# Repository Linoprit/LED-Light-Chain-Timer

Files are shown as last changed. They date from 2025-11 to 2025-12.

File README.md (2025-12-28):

# LED-Light-Chain-Timer
A simple timer for LED chains. Switch it on and the LED chain lights for 6h, then it turns off for 18h, and so on.

Our LED string lights were going through a ton of batteries every year.
On the other side, we had plenty of old power tool batteries that would otherwise have been thrown away.
So I looked for a solution to use those batteries.

The problem with lithium batteries, however, is that they can't be completely discharged, so you need a protection circuit.

That's how I came across the TP4096 Protection Board, which also includes a charging circuit.

With the sheer number of string lights we have in use, it turned out that a timer circuit was necessary to automatically switch them on and off.

But there was no chance to timers ready-made anywhere, even though they're often found in the battery compartments of LED string lights.

That's why I built my own.

The usage of a CH32V003J4M6 allows to directly connect the schematic to a 3.6V LiIon-Battery. 

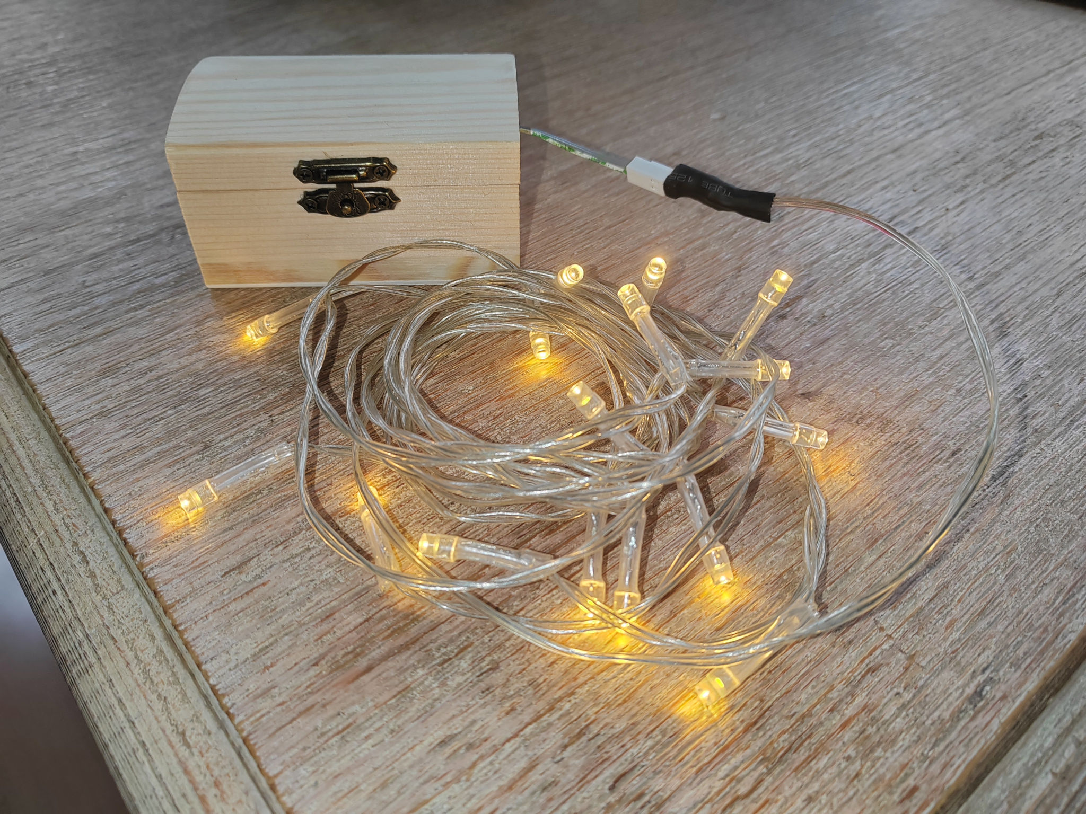
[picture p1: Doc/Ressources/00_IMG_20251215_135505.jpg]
 

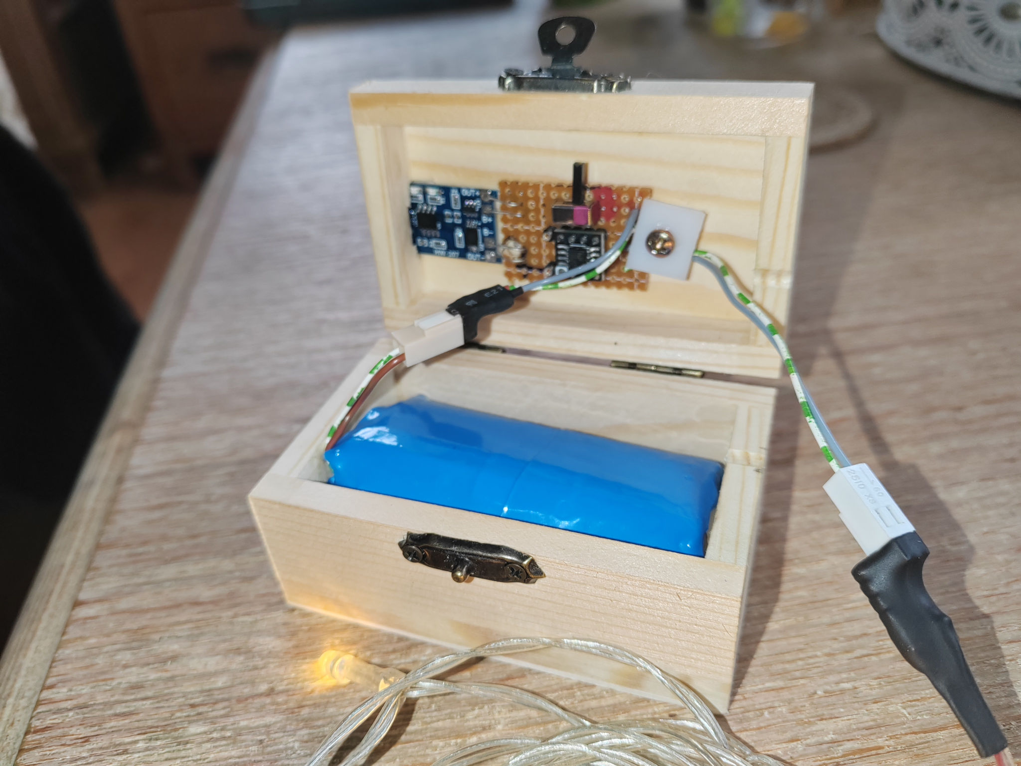
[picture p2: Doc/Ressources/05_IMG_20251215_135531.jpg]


To make it look nice, everything is packed in a wooden box.
The left image shows an older version with a switch. It turned out, that it could be omitted. 
The battery connection could therefore be soldered directly onto the protection board.
I built twenty of those timers, so this simplified things really. 

We could hide the plug of the LED string inside the housing, and of course run the cable to the outside through a hole.

Under the black heat shrink tubing, next to the connector, is a small piece of circuit board on which resistor limits the current through the LEDs to below 10mA. I set each of the different LED strings to this current, the brightness is okay like this. The values of the resistor varies from chain to chain and is approximately between 68 and 150 ohms. 

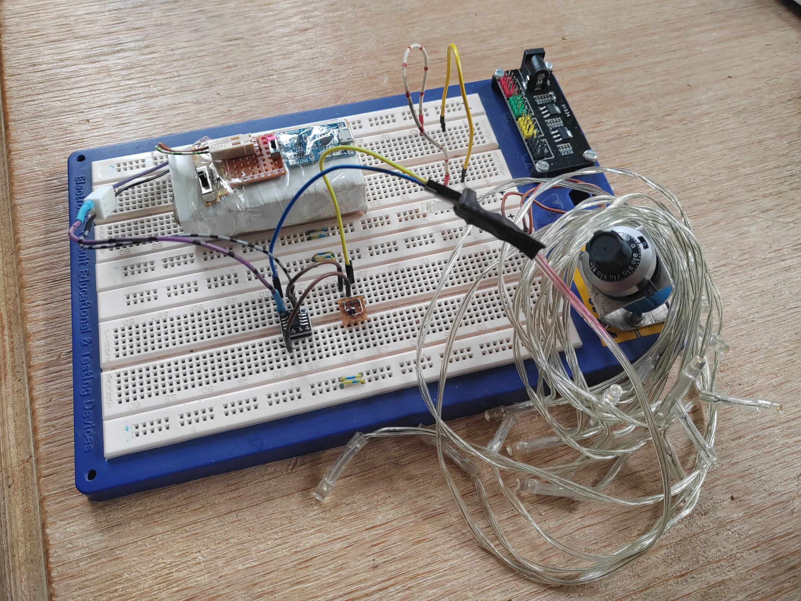
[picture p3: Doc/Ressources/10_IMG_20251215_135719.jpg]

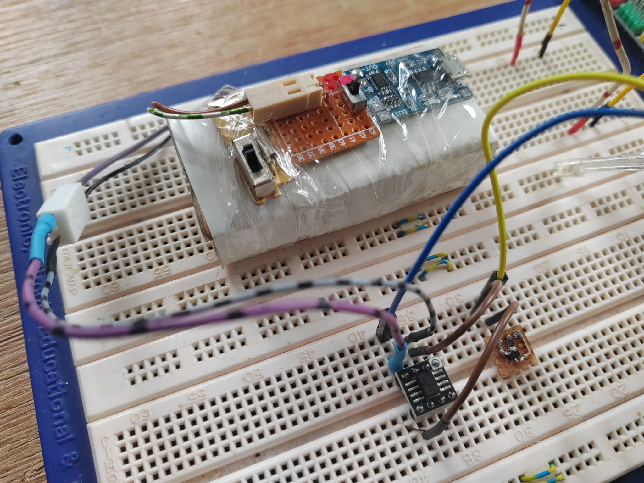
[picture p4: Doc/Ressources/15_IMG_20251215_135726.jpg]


Here is the breadboard setup shown, with a battery on which a TP4096 protection board is mounted.

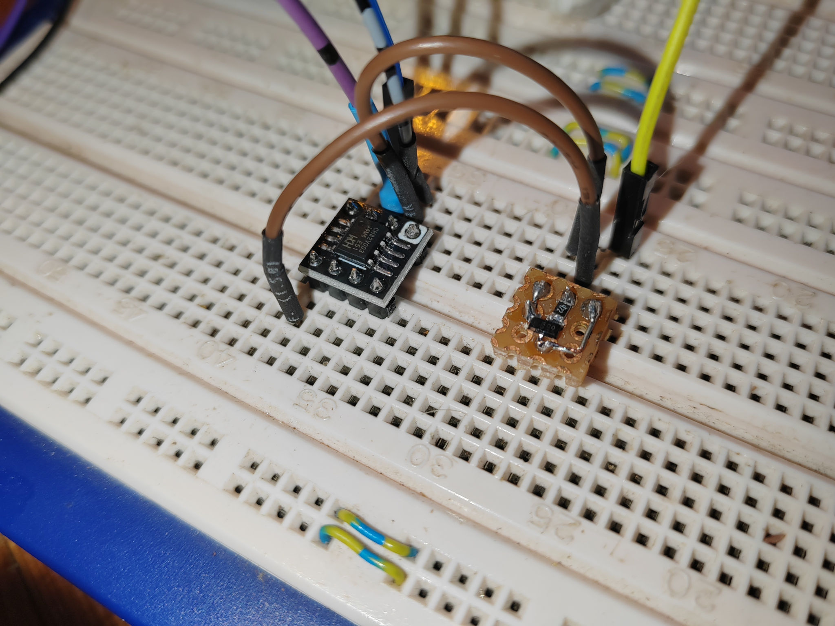
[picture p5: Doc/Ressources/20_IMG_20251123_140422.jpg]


On the left is the CH32v003J4N6 CPU, mounted on an adapter board. On the right is a transistor circuit, which was later omitted.

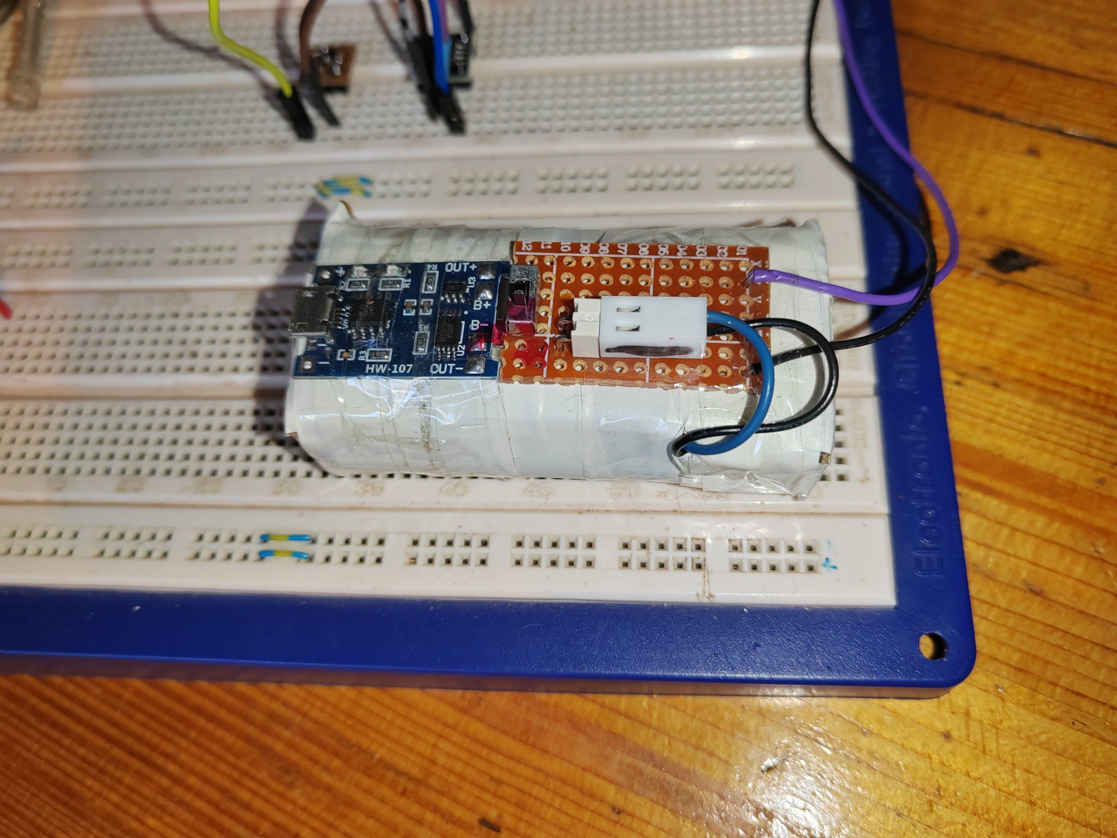
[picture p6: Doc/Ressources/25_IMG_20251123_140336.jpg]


Again, the battery with protection board.

## Parts you need, the links go to Aliexpress: 
- [CH32V003J4M6](https://de.aliexpress.com/item/1005008597052746.html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)
- [TP4056 Protection Board ()](https://de.aliexpress.com/item/1005007980101977.html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)
- [Adapter Boards for the CPUs](https://de.aliexpress.com/item/1005006991835764.html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)
- [Connectors](https://de.aliexpress.com/item/1005009345725922.html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)
- [Programmer](https://de.aliexpress.com/item/1005005180653105.html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)
> [!NOTE]
> You do need the WCH LinkE! The WCH-Link (without 'E') will not work.

Don't forget some boards, where you could solder everything on :-).

If you want a CPU with more pins use this one: [CH32V003F4P6](https://de.aliexpress.com/item/1005009062407508.html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)

## The Software...
...is really nothing special, there is only a main.c and a main.h. Simply use [PlatformIo](https://platformio.org/) to compile it. 

- [PIO Installation](https://platformio.org/install/ide)
- [PIO with VS Code ](https://platformio.org/platformio-ide)

You could use the Python script to measure some timings. Connect the TX-Pin of the CPU to the RX of the programmer. Then simply activate the defines in main.h. Don't activate both lines.

```
#define USE_UART_1MIN
#undef USE_UART_60MIN
```

I hope this little project is helpful to someone.

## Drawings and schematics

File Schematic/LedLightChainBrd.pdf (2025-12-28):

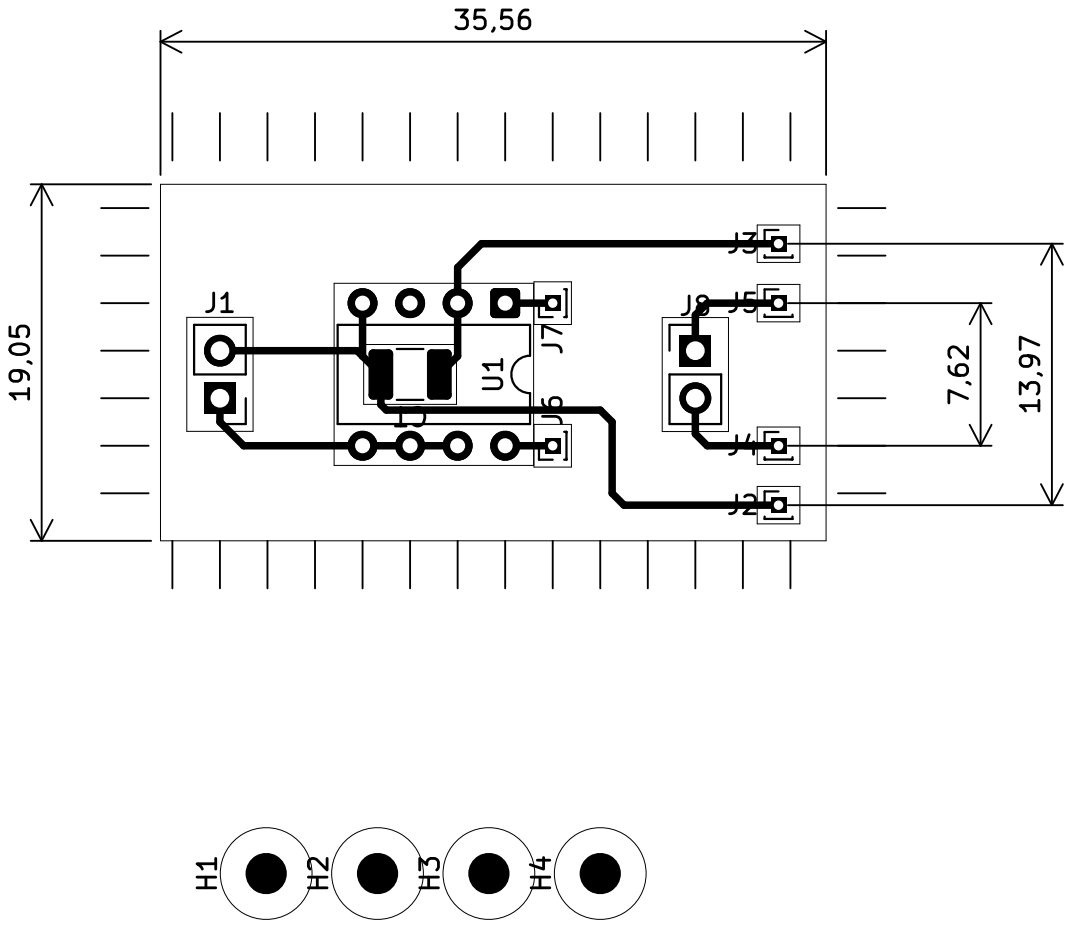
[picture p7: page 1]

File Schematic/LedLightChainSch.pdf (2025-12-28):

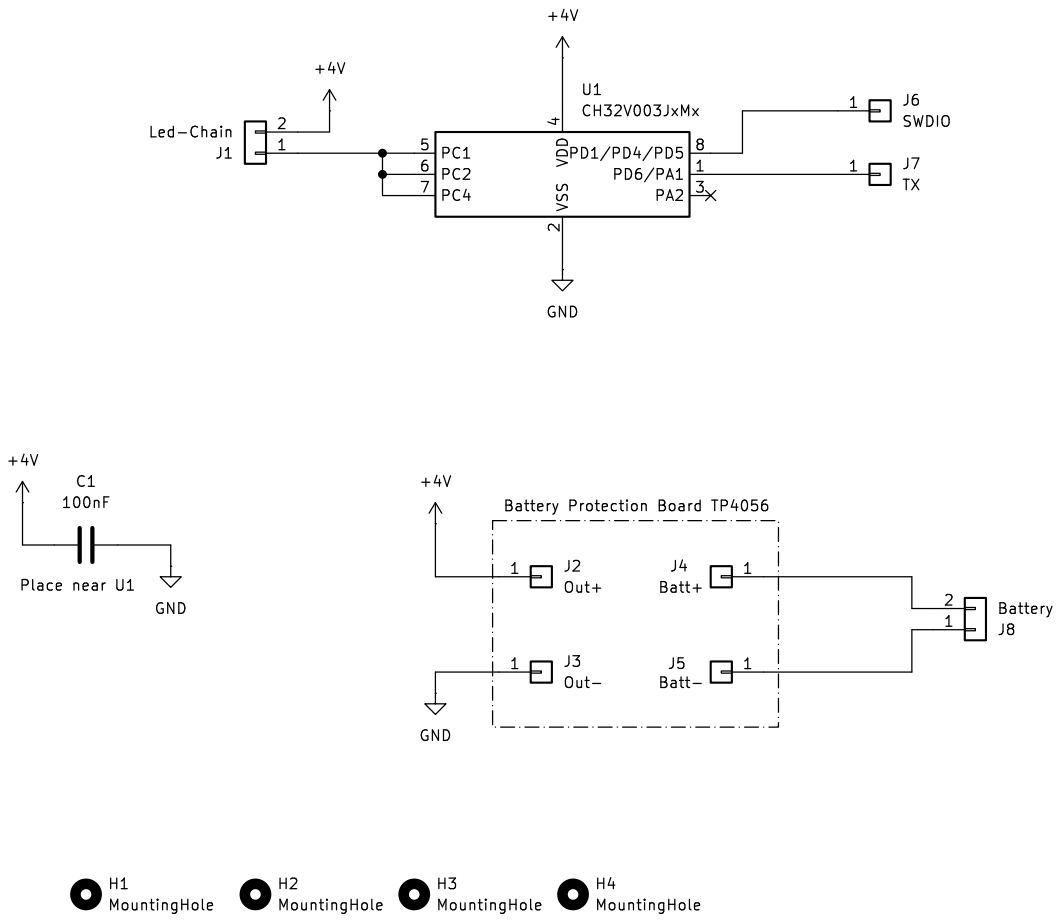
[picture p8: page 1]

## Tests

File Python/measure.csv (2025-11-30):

[B] Zeitdifferenz: 31 | 915 Sekunden
[B] Zeitdifferenz: 31 | 916 Sekunden
[B] Zeitdifferenz: 31 | 919 Sekunden
[B] Zeitdifferenz: 31 | 915 Sekunden
[B] Zeitdifferenz: 31 | 909 Sekunden
[B] Zeitdifferenz: 31 | 912 Sekunden
[B] Zeitdifferenz: 31 | 913 Sekunden
[B] Zeitdifferenz: 31 | 909 Sekunden
[B] Zeitdifferenz: 31 | 909 Sekunden
[B] Zeitdifferenz: 31 | 902 Sekunden
[B] Zeitdifferenz: 31 | 902 Sekunden
[B] Zeitdifferenz: 31 | 905 Sekunden
[B] Zeitdifferenz: 31 | 904 Sekunden
[B] Zeitdifferenz: 31 | 903 Sekunden
[B] Zeitdifferenz: 31 | 903 Sekunden
[B] Zeitdifferenz: 31 | 903 Sekunden
[B] Zeitdifferenz: 31 | 906 Sekunden
[B] Zeitdifferenz: 31 | 906 Sekunden
[B] Zeitdifferenz: 31 | 907 Sekunden
[B] Zeitdifferenz: 31 | 906 Sekunden
[B] Zeitdifferenz: 31 | 907 Sekunden
[B] Zeitdifferenz: 31 | 906 Sekunden
[B] Zeitdifferenz: 31 | 902 Sekunden

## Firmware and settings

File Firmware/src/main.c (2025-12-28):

/********************************** (C) COPYRIGHT *******************************
 * File Name          : main.c
 * Author             : WCH
 * Version            : V1.0.0
 * Date               : 2023/12/25
 * Description        : Main program body.
 *********************************************************************************
 * Copyright (c) 2021 Nanjing Qinheng Microelectronics Co., Ltd.
 * Attention: This software (modified or not) and binary are used for
 * microcontroller manufactured by Nanjing Qinheng Microelectronics.
 *******************************************************************************/

/*
 *@Note
 *CH32V003F4P6 - Interrupts
 *https://curiousscientist.tech/blog/ch32v003f4p6-interrupts
 */

#include "main.h"
#include "stdbool.h"

void countToTarget(uint32_t target);

void initializeTimer(uint16_t prsc, uint16_t arr)
{
    TIM_TimeBaseInitTypeDef TIM_TimeBaseStructure = {0};
    NVIC_InitTypeDef NVIC_InitStructure = {0};

    RCC_APB1PeriphClockCmd(RCC_APB1Periph_TIM2, ENABLE);

    TIM_TimeBaseStructure.TIM_Period = arr;
    TIM_TimeBaseStructure.TIM_Prescaler = prsc;
    TIM_TimeBaseStructure.TIM_ClockDivision = TIM_CKD_DIV1;
    TIM_TimeBaseStructure.TIM_CounterMode = TIM_CounterMode_Up;
    TIM_TimeBaseInit(TIM2, &TIM_TimeBaseStructure);

    TIM_SelectOutputTrigger(TIM2, TIM_TRGOSource_Update),
        TIM_ITConfig(TIM2, TIM_IT_Update, ENABLE);

    NVIC_InitStructure.NVIC_IRQChannel = TIM2_IRQn;
    NVIC_InitStructure.NVIC_IRQChannelPreemptionPriority = 0;
    NVIC_InitStructure.NVIC_IRQChannelSubPriority = 1;
    NVIC_InitStructure.NVIC_IRQChannelCmd = ENABLE;
    NVIC_Init(&NVIC_InitStructure);

    TIM_Cmd(TIM2, ENABLE);
}

#ifdef USE_UART_60MIN
const uint32_t targetPause = 3600 * 1;
const uint32_t targetActive = 3600 * 1;
#else
const uint32_t targetPause = 3600 * 18;
const uint32_t targetActive = 3600 * 6;
#endif

uint32_t actCount = 0;

#ifdef USE_UART_1MIN
bool done = false;
#endif

int main(void)
{
    NVIC_PriorityGroupConfig(NVIC_PriorityGroup_1);

    SystemCoreClockUpdate(); // initializeTimer(8049, 999); // 3612.578 Sekunden

    Delay_Init();
    Delay_Ms(1000);
    GPIOConfig();

#if defined(USE_UART_1MIN) || defined(USE_UART_60MIN)
    USART_Printf_Init(115200);
    printf("CH32V003 - Timer test\n");
#endif

#ifdef CRYSTAL
    initializeTimer(2666, 999); // 1kHz, 1s period
#endif
#ifdef BUILDIN_RC
    initializeTimer(8023, 999); // 1kHz, 1s period
#endif

    for (uint_fast8_t i = 0; i < 4; i++)
    {
        SwitchFairyPins(FAIRY_ON);
        Delay_Ms(300);
        SwitchFairyPins(FAIRY_OFF);
        Delay_Ms(300);
    }

    while (1)
    {
#ifdef USE_UART_60MIN
        printf("A\n");
#endif

        SwitchFairyPins(FAIRY_ON);
        countToTarget(targetActive);

#ifdef USE_UART_60MIN
        printf("B\n");
        printf("A\n");
#endif

        SwitchFairyPins(FAIRY_OFF);
        countToTarget(targetPause);

#ifdef USE_UART_60MIN
        printf("B\n");
#endif
    }
}

void countToTarget(uint32_t target)
{
#ifdef USE_UART_1MIN
    const uint32_t moduloCount = 60;
    printf("A\n");
#endif

    actCount = 0;
    while (actCount < target)
    {
        Delay_Ms(5);

#ifdef USE_UART_1MIN
        if (((actCount % moduloCount) == 0) && done == false)
        {
            done = true;
            printf("B\n");
            printf("A\n");
        }
        if ((actCount % moduloCount) != 0)
        {
            done = false;
        }
#endif
    }
}

void TIM2_IRQHandler(void) __attribute__((interrupt("WCH-Interrupt-fast")));
void TIM2_IRQHandler(void)
{
    if (TIM_GetITStatus(TIM2, TIM_IT_Update) != RESET)
    {
        TIM_ClearITPendingBit(TIM2, TIM_IT_Update);
        actCount++;

#ifdef F4P6
        GPIO_WriteBit(BLINKY_GPIO_PORT, BLINKY_GPIO_PIN,
                      (GPIO_ReadOutputDataBit(BLINKY_GPIO_PORT, BLINKY_GPIO_PIN) == Bit_SET) ? Bit_RESET : Bit_SET);
#endif
    }
}

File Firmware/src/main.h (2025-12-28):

#include <ch32v00x.h>
#include <debug.h>
#include <stdbool.h>


#undef USE_UART_1MIN
#undef USE_UART_60MIN

// Definitions to allow easy adjustment
#define BLINKY_GPIO_PORT GPIOD
#define BLINKY_GPIO_PIN GPIO_Pin_2
#define LED_FAIRY_PORT GPIOC
#ifdef J4M6
#define LED_FAIRY_PIN_01 GPIO_Pin_1
#define LED_FAIRY_PIN_02 GPIO_Pin_2
#define LED_FAIRY_PIN_03 GPIO_Pin_4
#else
#define LED_FAIRY_PIN GPIO_Pin_1
#define LED_FAIRY_PIN GPIO_Pin_2
#define LED_FAIRY_PIN GPIO_Pin_3
#endif
#define BLINKY_ON 1u
#define BLINKY_OFF 0u
#define FAIRY_ON 0u
#define FAIRY_OFF 1u
// #define BLINK_LENGTH_MS 100

// Error codes
#define OK 0
#define ERR_OUT_OF_RANGE 1

int main(void);
void parse_USART(void);

void NMI_Handler(void) __attribute__((interrupt("WCH-Interrupt-fast")));
void HardFault_Handler(void) __attribute__((interrupt("WCH-Interrupt-fast")));

void SwitchFairyPins(uint_fast8_t OnOrOff){
    GPIO_WriteBit(LED_FAIRY_PORT, LED_FAIRY_PIN_01, OnOrOff);
    GPIO_WriteBit(LED_FAIRY_PORT, LED_FAIRY_PIN_02, OnOrOff);
    GPIO_WriteBit(LED_FAIRY_PORT, LED_FAIRY_PIN_03, OnOrOff);
}

void GPIOConfig()
{
    GPIO_InitTypeDef GPIO_InitStructure = {0};

    RCC_APB2PeriphClockCmd(
        RCC_APB2Periph_GPIOA | RCC_APB2Periph_GPIOC | RCC_APB2Periph_GPIOD, ENABLE);
    RCC_APB1PeriphClockCmd(RCC_APB1Periph_PWR, ENABLE);
    GPIO_InitStructure.GPIO_Pin = GPIO_Pin_All;   // Apply the settings on all pins under the selected port
    GPIO_InitStructure.GPIO_Mode = GPIO_Mode_IPU; // Internal pull-up -> Contributes to power saving
    GPIO_Init(GPIOA, &GPIO_InitStructure);
    GPIO_Init(GPIOC, &GPIO_InitStructure);
    GPIO_Init(GPIOD, &GPIO_InitStructure);

    // ---------
    GPIO_InitStructure.GPIO_Mode = GPIO_Mode_Out_PP;
    GPIO_InitStructure.GPIO_Speed = GPIO_Speed_2MHz;

#ifdef F4P6
    GPIO_InitStructure.GPIO_Pin = BLINKY_GPIO_PIN;
    GPIO_Init(BLINKY_GPIO_PORT, &GPIO_InitStructure);
    GPIO_WriteBit(BLINKY_GPIO_PORT, BLINKY_GPIO_PIN, BLINKY_OFF);
#endif

    // ---------
    GPIO_InitStructure.GPIO_Pin = LED_FAIRY_PIN_01;
    GPIO_Init(LED_FAIRY_PORT, &GPIO_InitStructure);
    SwitchFairyPins(FAIRY_OFF);

    // remap UTX pin to PD6 on J4M6
#if (defined(USE_UART_1MIN) || defined(USE_UART_60MIN)) && defined J4M6
    RCC_APB2PeriphClockCmd(
        RCC_APB2Periph_GPIOD | RCC_APB2Periph_USART1 | RCC_APB2Periph_AFIO, ENABLE);
    GPIO_PinRemapConfig(GPIO_PartialRemap2_USART1, ENABLE);

    GPIO_InitStructure.GPIO_Pin = GPIO_Pin_6;
    GPIO_InitStructure.GPIO_Speed = GPIO_Speed_30MHz;
    GPIO_InitStructure.GPIO_Mode = GPIO_Mode_AF_PP;
    GPIO_Init(GPIOD, &GPIO_InitStructure);
#endif
}

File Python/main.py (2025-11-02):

import serial
import time
from datetime import datetime

# Konfiguration der seriellen Schnittstelle
SERIAL_PORT = '/dev/ttyACM0'  # unter Windows z. B. 'COM3'
BAUDRATE = 115200               # Anpassen je nach Konfiguration
#BAUDRATE = 38400

def main():
    start_time = None
    buffer = ""

    try:
        with serial.Serial(SERIAL_PORT, BAUDRATE, timeout=1) as ser:
            print(f"Höre auf {SERIAL_PORT} mit {BAUDRATE} Baudrate...")

            while True:
                if ser.in_waiting > 0:
                    char = ser.read(1).decode(errors='ignore')
                    buffer += char

                    if char == '\n':
                        line = buffer.strip()
                        buffer = ""

                        if line == 'A':
                            start_time = datetime.now()
                            print(f"[A] Startzeit gespeichert: {start_time.strftime('%H:%M:%S.%f')[:-3]}")

                        elif line == 'B':
                            if start_time:
                                end_time = datetime.now()
                                delta = end_time - start_time
                                print(f"[B] Zeitdifferenz: {delta.total_seconds():.3f} Sekunden")
                            else:
                                print("[B] Fehler: Startzeit wurde noch nicht empfangen.")

                        else:
                            print(f"Unbekannte Nachricht empfangen: {line}")

                time.sleep(50 / 1000)
    except serial.SerialException as e:
        print(f"Fehler beim Zugriff auf die serielle Schnittstelle: {e}")
    except KeyboardInterrupt:
        print("\nBeendet durch Benutzer.")

if __name__ == "__main__":
    main()

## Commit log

2025-11-23 Release with target hardware
    [LedLightChainSch.kicad_sch, LedLightChainSch_SMD.kicad_pcb]
2025-11-30 PCB Battery-Board connections fixed.
    [LedLightChainSch.kicad_pcb, LedLightChainSch.kicad_sch, measure.csv]
2025-12-28 Transistor removed
    [LedLightChainSch.kicad_pcb, LedLightChainSch.kicad_sch]
2025-12-28 Connectors added
